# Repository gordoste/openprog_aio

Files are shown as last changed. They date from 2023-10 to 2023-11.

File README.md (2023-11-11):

# openprog_aio
All-in-one variant of Alberto Maccioni's wonderful Openprog PIC/AVR programmer (http://openprog.altervista.org/).

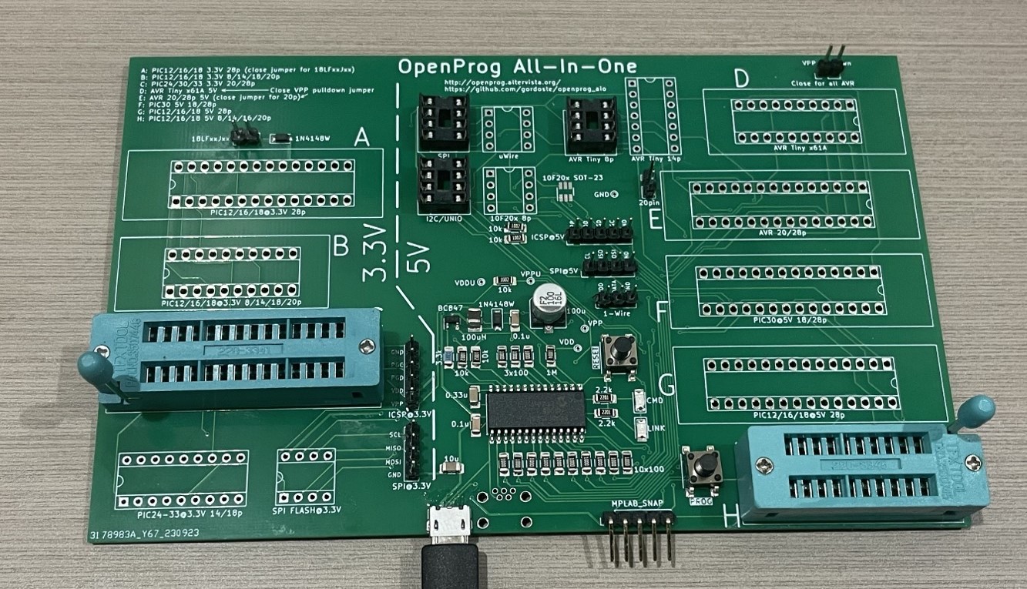
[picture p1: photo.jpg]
Photo of board


## Benefits

For low-voltage programming, the big advantage of this programmer over something like the MPLAB Snap is that it can provide power to the target device, and all of the surrounding circuitry (bypass caps, etc.) is built onto the board. You just plug in a device and program it.

The programmer is also fully capable of high-voltage programming. This is essential if you need to program an older device, and it also means you can use the MCLR pin as an extra I/O, which can be very handy on low-pin-count devices.

This version is aimed at allowing you to get started for the lowest cost and without making your own PCBs. Therefore, the following changes have been made from the original project:

* No adapter boards - just one board, making it cheaper to order from PCB fabrication shops.
* Board is still reasonable size at 158x100mm - approx twice the size of the original project's main board
* Designed to be easily hand-soldered, with 1206 size SMD components. The trickiest thing to solder is the USB socket. You shouldn't need any special equipment if you have clear vision and good lighting - just 0.3mm solder, flux paste and de-soldering braid. NOTE: If you are hand-soldering, it is recommended to use a USB Mini-B socket - see [Part List](#part-list).
* Documentation is on the board, including clear delineation between 5V/3.3V
* Ability to use ZIF sockets for all 20/28 pin sockets if desired.
* PROG button can be used even if device is programmed in low-voltage mode (previously it was attached to RE3/#MCLR)
* ICSP inputs match the MPLAB Snap pinout (different from PICKit).

Please note that the 40-pin Wide DIP sockets have been removed as those devices are rarely used now and took up too much room. If you want to program those devices, you can easily connect the ICSP output to a breadboard.

## Before you start

You need temporary access to a PIC programmer to construct this project. If you don't have a friend with a programmer, the MPLAB Snap is the cheapest commercial option.

## Schematic

The schematic is [here](schematic.pdf).

## Firmware

The original firmware uses unsupported tooling (MCC). I have ported the firmware to MPLAB X and it is available at <https://github.com/gordoste/openprog>. All testing of this board is conducted using this firmware, and testing status of the board/firmware combo can be found at the firmware repository.

## Part List

You can copy and paste [this part list](bom/partlist.txt) into Mouser's BOM tool to order the passive components and semiconductors. In addition to those, you will need the following which are best ordered from AliExpress or similar:
1. IC sockets. You may wish to only populate the sockets you use. Here is a list of all of the sockets:
   | Socket ID | Socket pin count | Device family | Voltage | Device pin count | Can be ZIF? |
   | ----------|------------------|---------------|---------|------------------|-------------|
   | A | 28 | PIC12/16/18 | 3.3V | 28 | Y  |
   | B | 20 | PIC12/16/18 | 3.3V | 8/14/18/20 | Y |
   | C | 28 | PIC24/30/33 | 3.3V | 20/28 | Y |
   | D | 20 | AVR Tiny x61A | 5V | 20 | Y |
   | E | 28 | AVR | 5V | 20/28 | Y |
   | F | 28 | PIC30 | 5V | 18/28 | Y |
   | G | 28 | PIC12/16/18 | 5V | 28 | Y |
   | H | 20 | PIC12/16/18 | 5V | 8/14/16/20 | Y |
   | - | 18 | PIC24-33 | 3.3V | 14/18 | N |
   | - | 8  | SPI Flash | 3.3V | 8 | N |
   | - | 8  | SPI Flash | 5V | 8 | N |
   | - | 8  | uWire Flash | 5V | 8 | N |
   | - | 8  | I2C/UNIO Flash | 5V | 8 | N |
   | - | 8  | PIC 10F20x | 5V | 8 | N |
   | - | 8  | AVR Tiny | 5V | 8 | N |
   | - | 14 | AVR Tiny | 5V | 14 | N |
2. 2.54mm (0.1") pitch pin headers. 3 x 2-pin, 3 x 5-pin, 2 x 4-pin and 1 x 3-pin (all straight). Optionally, you can use a 90-degree header for the 5-pin MPLAB Snap connector.
3. one 6x6mm SMD push button for the PROG button (two if you choose to fit the RESET button)
4. USB socket - either thru-hole Mini-B (I got some from AliExpress which worked fine) or SMD Micro-B (GCT part # USB3076-30-A) (this has fine-pitch pins and is not easy to hand-solder).

## Construction Notes

Download the [ZIP file](https://github.com/gordoste/openprog_aio/releases/download/v1.0b/Openprog_All-in-one_1.0b.zip) containing the PCB gerber files and submit it to your favourite production house.

You can use [this interactive BOM](ibom.html) to assist in placing parts.

Assuming you are hand-soldering, solder the parts in the following order:
1. Back side: Transistors, diodes, resistors, capacitors, regulator
2. Front side: Transistors, diodes, resistors, LEDs, ceramic capacitors, inductor, PIC18F25K50, button(s), electrolytic cap, USB socket, pin headers.

Be careful to only apply a small amount of solder when soldering the USB socket, as it is very easy to create a bridge. Don't panic if you do - turn your soldering iron up a bit hotter than normal, apply a liberal amount of flux and then use desolder braid to try to get rid of __all__ of the solder from the bridged pins. Once it's cleaned up, try again with less solder.

After you've soldered everything, download the HEX file from the [firmware repository](https://github.com/gordoste/openprog) and program it onto the PIC. The marked "MPLAB_SNAP" connector matches the pinout of the Snap (as shown below) - if you're using a PICKit then you will need to utilise jumper wires to connect the programmer.

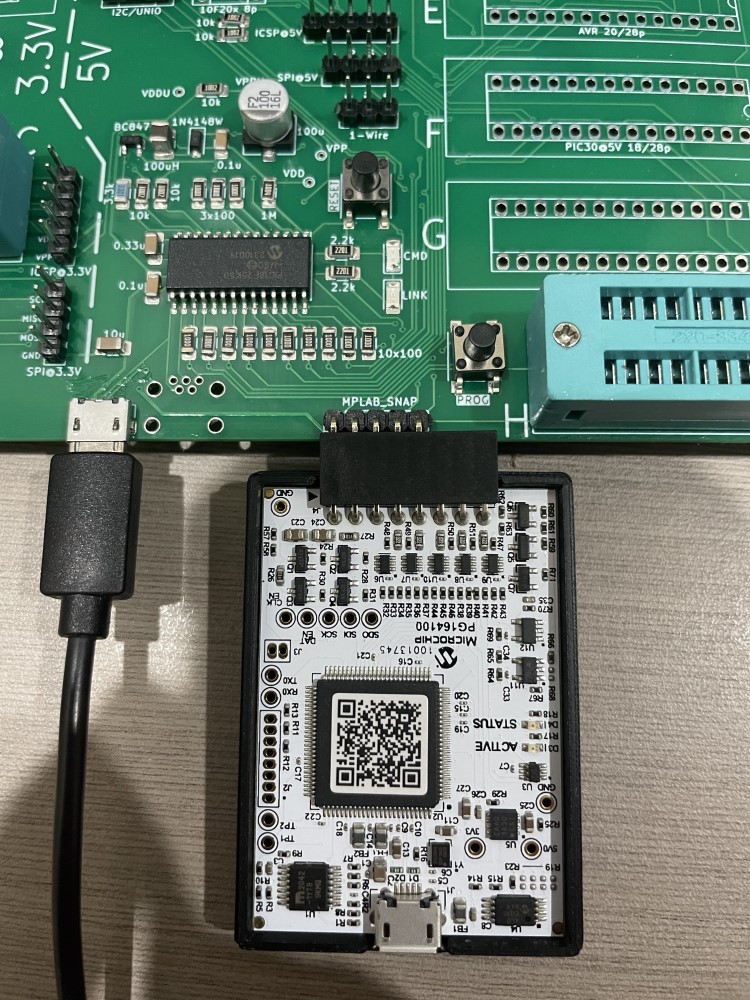
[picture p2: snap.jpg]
MPLAB Snap attached for programming


Assuming you've done everything right, when you plug it into your PC, it should show up as "Open Programmer" and the openprog GUI should be able to talk to it. I recommend using the command line "op" tool with the "-HWtest" option to run through basic checks before actually trying to program anything. See the [openprog webpage](http://openprog.altervista.org/) for more information.

## Usage Notes

### Programming 3.3V I2C EEPROMs

The original project did not provide a socket for this, and I have not yet added one. You can use the SPI@3.3V pin header and connect the following:
|Header pin|Device pin|
|---|---|
|GND|GND (4)|
|SCL|SCL (6)|
|MISO|SDA (5)|

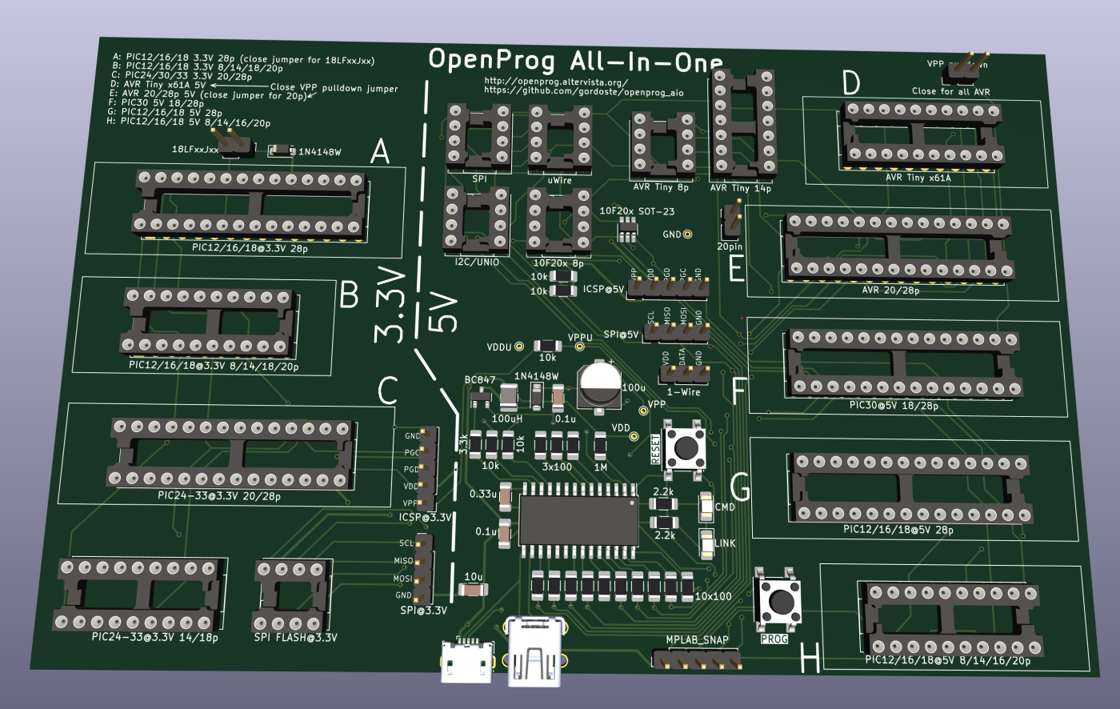
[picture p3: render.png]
Board render in KiCAD


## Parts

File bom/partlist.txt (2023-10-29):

579-PIC18F25K50-I/SO	1
80-C1206C104K5R7210	14
187-CL31A106KOHNNNE	4
187-CL31B334KBFNNNE	1
652-CR1206FX-1004ELF	1
652-CR1206FX-3303ELF	2
652-CR1206FX-1003ELF	1
652-CR1206FX-2202ELF	1
652-CR1206FX-1202ELF	1
652-CR1206FX-1002ELF	8
652-CR1206FX-2201ELF	2
791-RMC1/8K1000FTP	13
652-CR1206FX-1001ELF	7
652-CR1206FX-3301ELF	1
963-LBC3225T101KR	1
833-1N4148W-TP	9
710-150120BS75000	1
710-150120RS75000	1
863-BC857CLT1G	2
771-BC847B-T/R	2
710-865080343009	1

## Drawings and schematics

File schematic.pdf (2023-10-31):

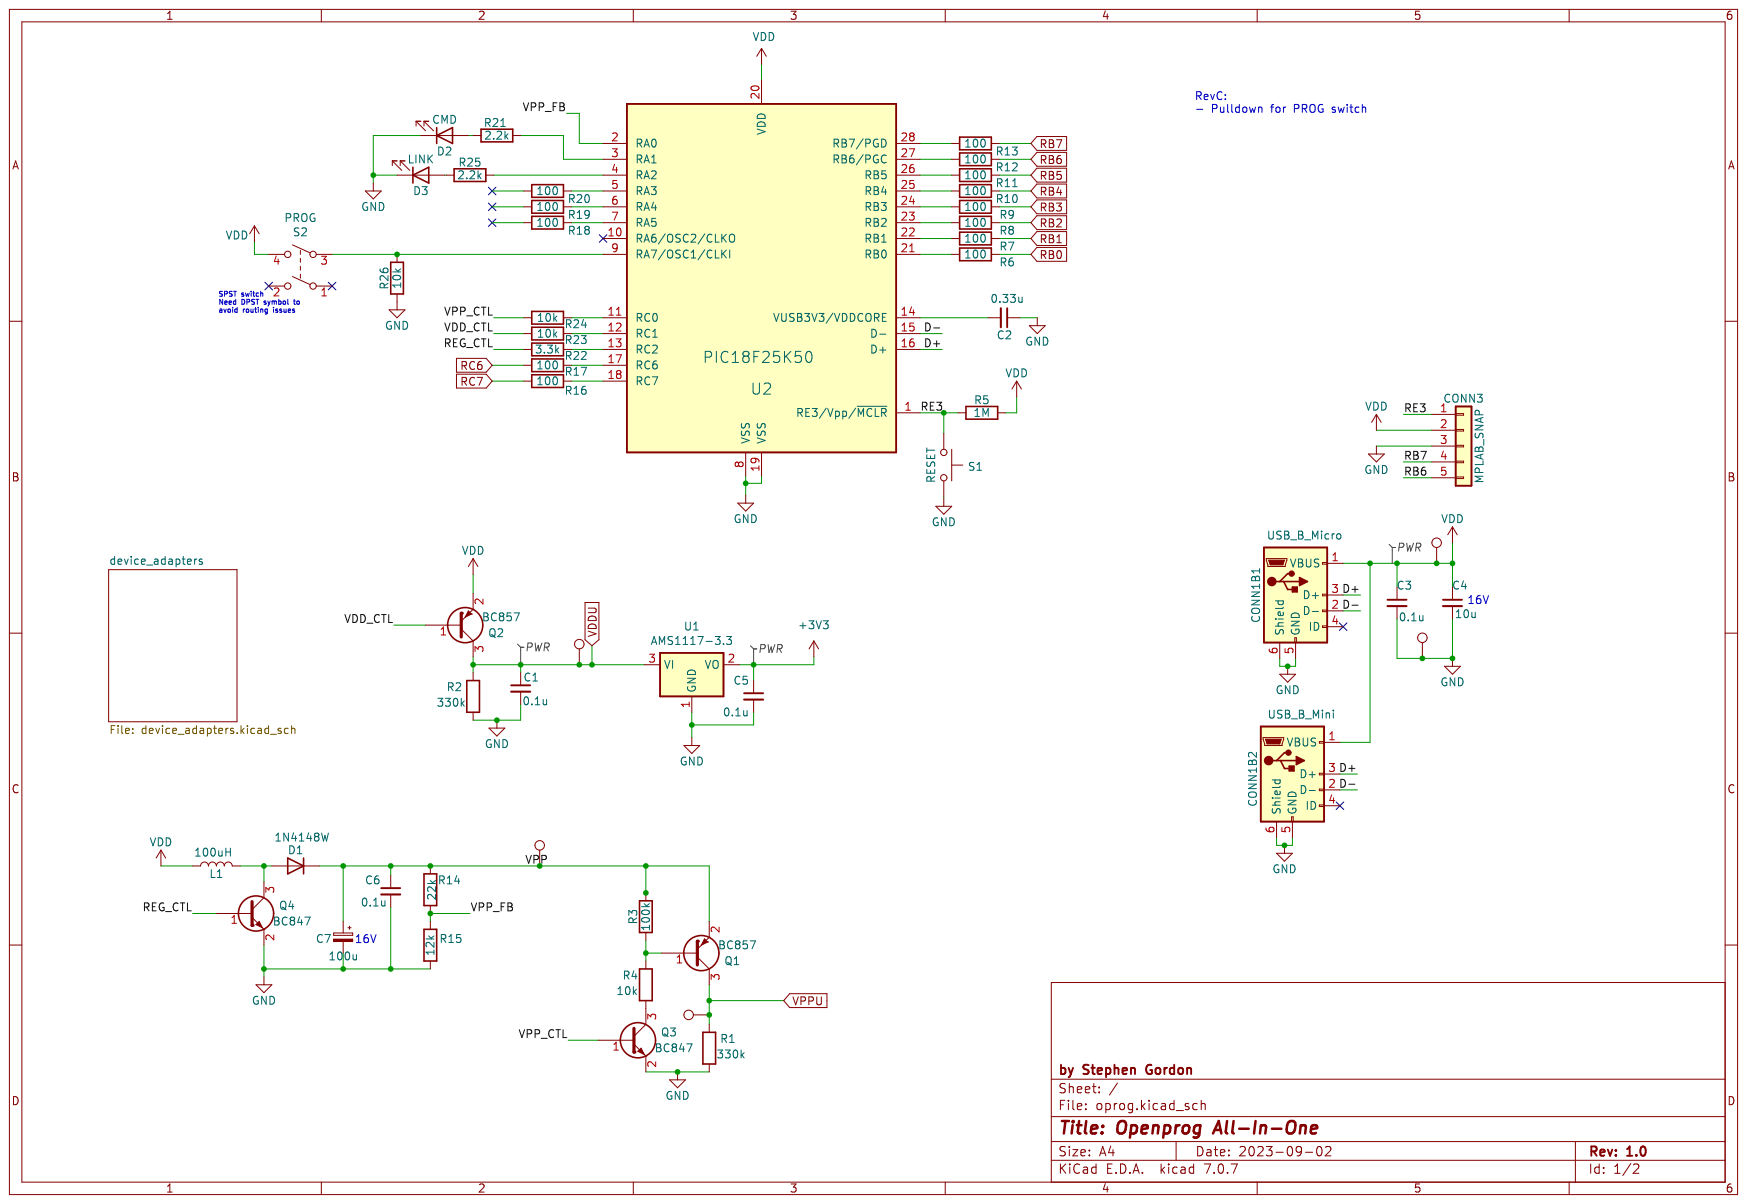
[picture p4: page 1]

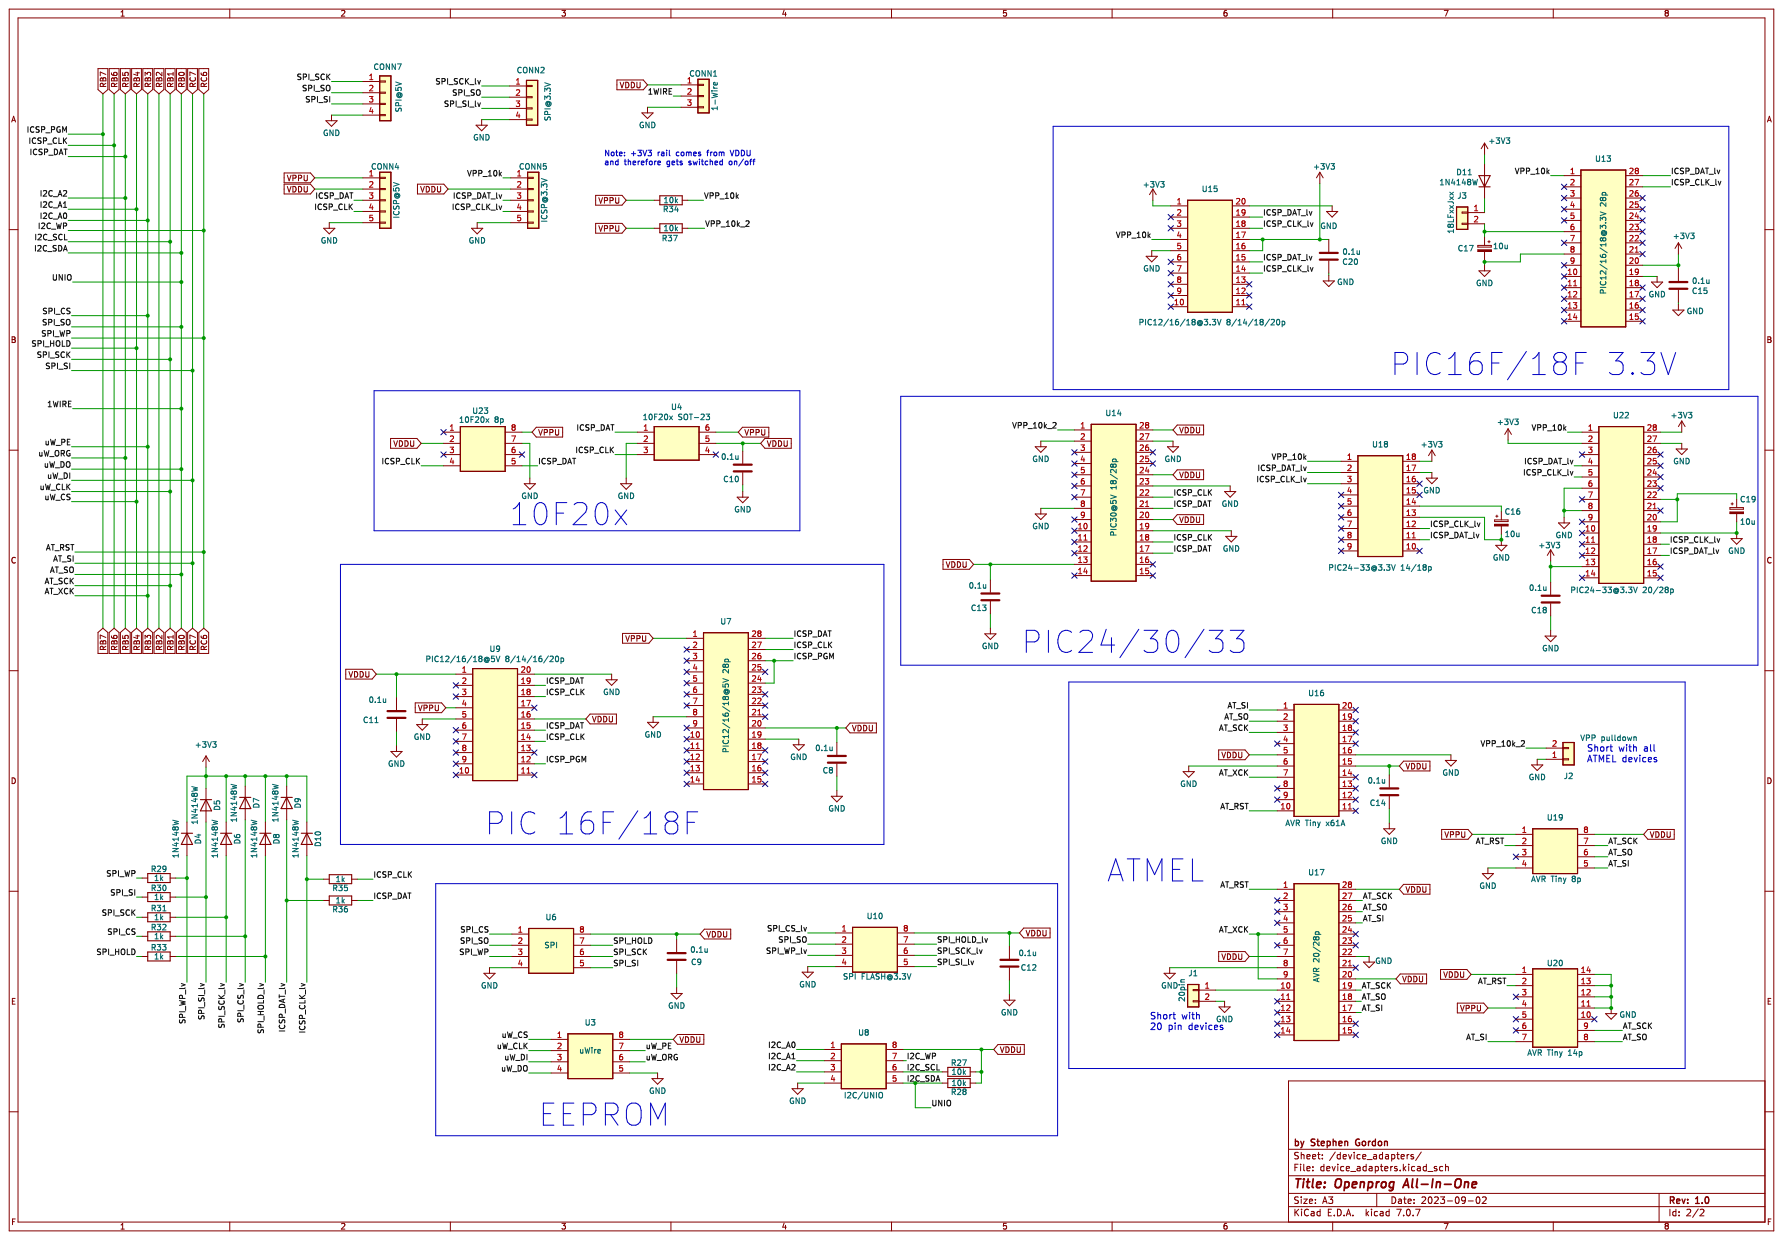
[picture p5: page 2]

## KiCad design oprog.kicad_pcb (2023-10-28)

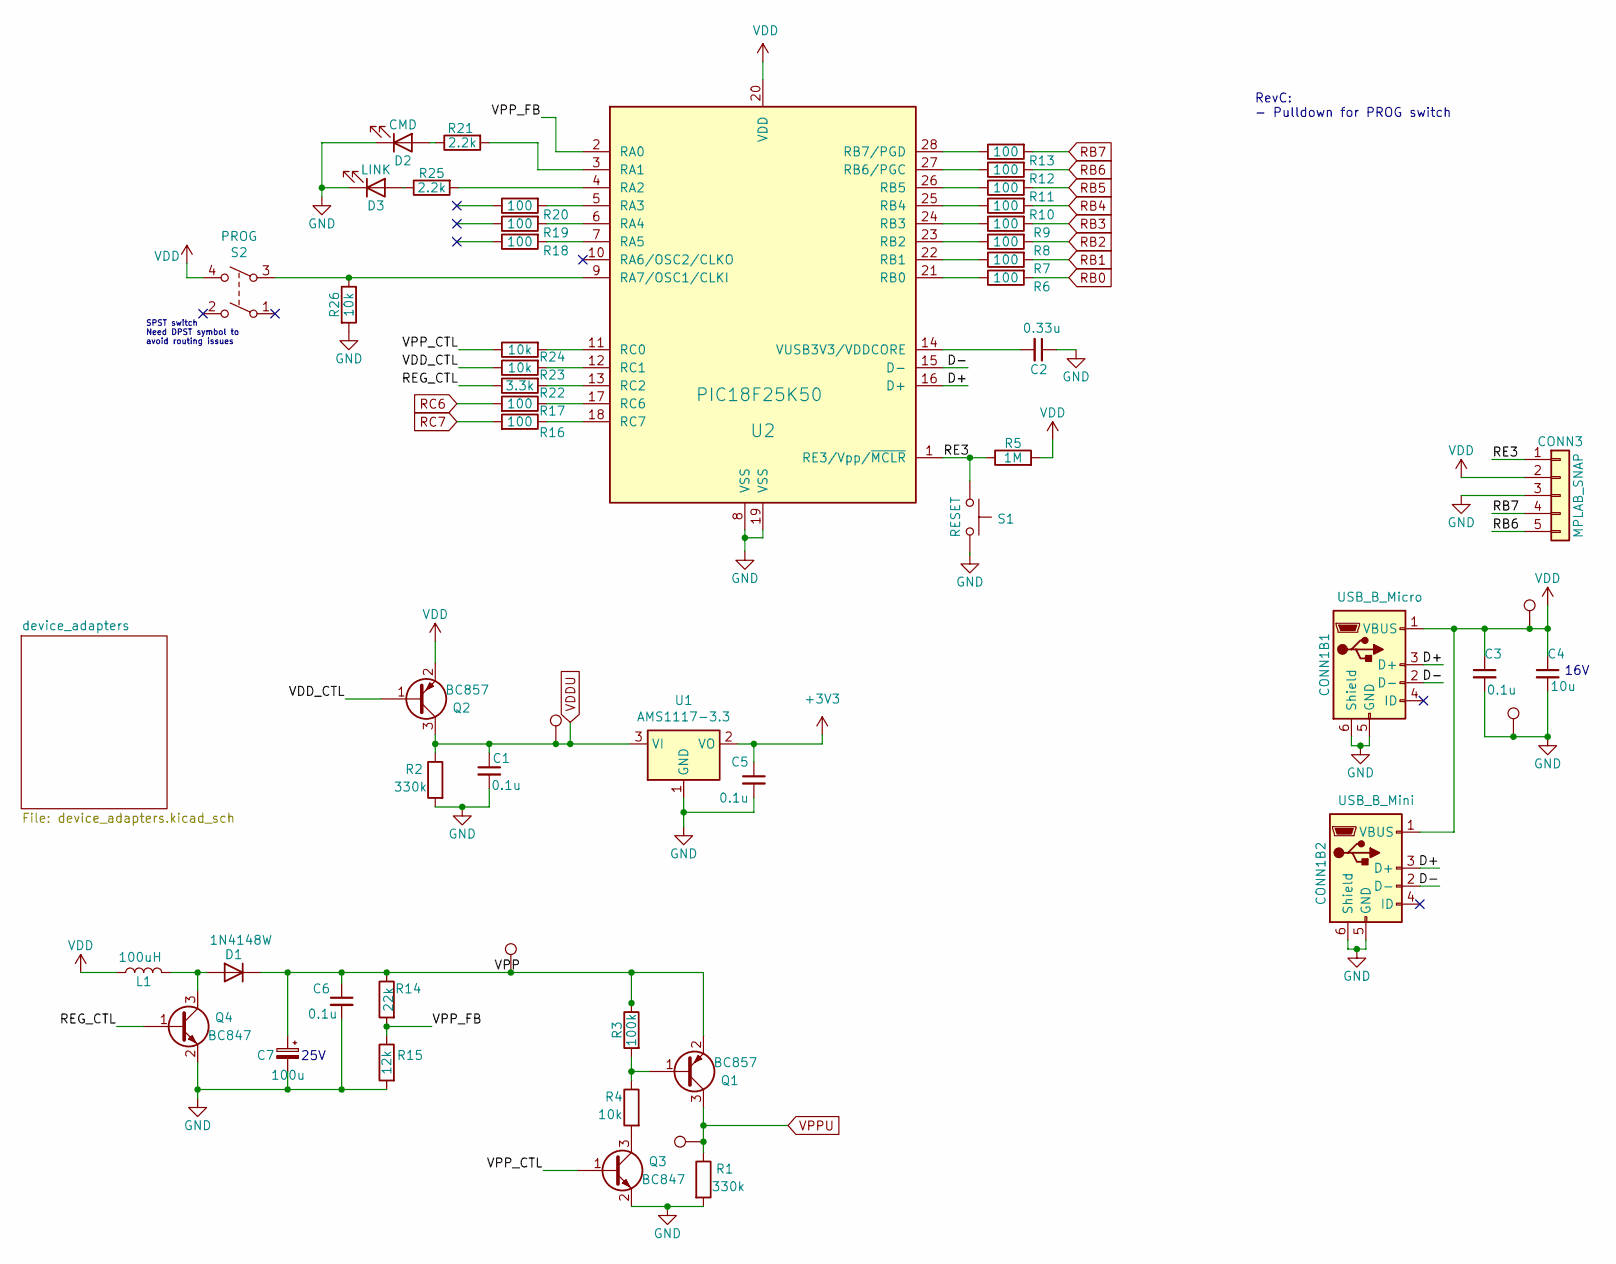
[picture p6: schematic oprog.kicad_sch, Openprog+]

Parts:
C1, C3, C5, C6: 0.1u; C_1206_3216Metric_Pad1.33x1.80mm_HandSolder
C2: 0.33u; C_1206_3216Metric_Pad1.33x1.80mm_HandSolder
C4: 10u; C_1206_3216Metric_Pad1.33x1.80mm_HandSolder
C7: 100u; CP_Elec_6.3x5.7
CONN1B1: USB_B_Micro; USB_Micro-B_GCT_USB3076-30-A
CONN1B2: USB_B_Mini; USB_Mini_Type_B_Aliexpress
CONN3: MPLAB_SNAP; PinHeader_1x05_P2.54mm_Vertical
D1: 1N4148W; D_SOD-123
D2: CMD; LED_1206_3216Metric_Pad1.42x1.75mm_HandSolder
D3: LINK; LED_1206_3216Metric_Pad1.42x1.75mm_HandSolder
L1: 100uH; L_1210_3225Metric_Pad1.42x2.65mm_HandSolder
Q1, Q2: BC857; SOT-23
Q3, Q4: BC847; SOT-23
R1, R2: 330k; R_1206_3216Metric_Pad1.30x1.75mm_HandSolder
R3: 100k; R_1206_3216Metric_Pad1.30x1.75mm_HandSolder
R4, R23, R24, R26: 10k; R_1206_3216Metric_Pad1.30x1.75mm_HandSolder
R5: 1M; R_1206_3216Metric_Pad1.30x1.75mm_HandSolder
R6, R7, R8, R9, R10, R11, R12, R13, R16, R17, R18, R19, R20: 100; R_1206_3216Metric_Pad1.30x1.75mm_HandSolder
R14: 22k; R_1206_3216Metric_Pad1.30x1.75mm_HandSolder
R15: 12k; R_1206_3216Metric_Pad1.30x1.75mm_HandSolder
R21, R25: 2.2k; R_1206_3216Metric_Pad1.30x1.75mm_HandSolder
R22: 3.3k; R_1206_3216Metric_Pad1.30x1.75mm_HandSolder
S1: RESET; SW_Push_1P1T_NO_6x6mm_2pads
S2: PROG; SW_Push_1P1T_NO_6x6mm_4pads
TP1: VPPU; TestPoint_THTPad_D1.0mm_Drill0.5mm
TP2: GND; TestPoint_THTPad_D1.0mm_Drill0.5mm
TP3: VDD; TestPoint_THTPad_D1.0mm_Drill0.5mm
TP7: VPP; TestPoint_THTPad_D1.0mm_Drill0.5mm
TP8: VDDU; TestPoint_THTPad_D1.0mm_Drill0.5mm
U1: AMS1117-3.3; SOT-223-3_TabPin2
U2: PIC18F25K50; SOIC-28W_7.5x17.9mm_P1.27mm

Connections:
+3V3: C5.1, U1.2 (VO); also elsewhere on the board
/D+: CONN1B1.3 (D+), CONN1B2.3 (D+), U2.16 (D+)
/D-: CONN1B1.2 (D-), CONN1B2.2 (D-), U2.15 (D-)
/RE3: CONN3.1, R5.1, S1.2, U2.1 (RE3/Vpp/~MCLR)
/REG_CTL: Q4.1 (B), R22.1
/VDD_CTL: Q2.1 (B), R23.1
/VPP: C6.1, C7.1, D1.1 (K), Q1.2 (E), R3.1, R14.1, TP7.1
/VPP_CTL: Q3.1 (B), R24.1
/VPP_FB: R14.2, R15.1, U2.2 (RA0)
GND: C1.2, C2.1, C3.2, C4.2, C5.2, C6.2, C7.2, CONN1B1.5 (GND), CONN1B1.6 (Shield), CONN1B2.5 (GND), CONN1B2.6 (Shield), CONN3.3, D2.1 (K), D3.1 (K), Q3.2 (E), Q4.2 (E), R1.2, R2.2, R15.2, R26.2, S1.1, TP2.1, U1.1 (GND), U2.8 (VSS), U2.19 (VSS); also elsewhere on the board
unnamed: D1.2 (A), L1.1, Q4.3 (C)
unnamed: D2.2 (A), R21.1
unnamed: D3.2 (A), R25.1
unnamed: Q1.1 (B), R3.2, R4.1
unnamed: Q3.3 (C), R4.2
unnamed: R21.2, U2.3 (RA1)
unnamed: R25.2, U2.4 (RA2)
unnamed: R20.2, U2.5 (RA3)
unnamed: R19.2, U2.6 (RA4)
unnamed: R18.2, U2.7 (RA5)
unnamed: R26.1, S2.3, U2.9 (RA7/OSC1/CLKI)
unnamed: R6.1, U2.21 (RB0)
unnamed: R7.1, U2.22 (RB1)
unnamed: R8.1, U2.23 (RB2)
unnamed: R9.1, U2.24 (RB3)
unnamed: R10.1, U2.25 (RB4)
unnamed: R11.1, U2.26 (RB5)
unnamed: R12.1, U2.27 (RB6/PGC)
unnamed: R13.1, U2.28 (RB7/PGD)
unnamed: R24.2, U2.11 (RC0)
unnamed: R23.2, U2.12 (RC1)
unnamed: R22.2, U2.13 (RC2)
unnamed: R17.1, U2.17 (RC6)
unnamed: R16.1, U2.18 (RC7)
unnamed: C2.2, U2.14 (VUSB3V3/VDDCORE)
RB0: R6.2; also elsewhere on the board
RB1: R7.2; also elsewhere on the board
RB2: R8.2
RB3: R9.2; also elsewhere on the board
RB4: R10.2; also elsewhere on the board
RB5: R11.2; also elsewhere on the board
RB6: CONN3.5, R12.2; also elsewhere on the board
RB7: CONN3.4, R13.2; also elsewhere on the board
RC6: R17.2; also elsewhere on the board
RC7: R16.2; also elsewhere on the board
VDD: C3.1, C4.1, CONN1B1.1 (VBUS), CONN1B2.1 (VBUS), CONN3.2, L1.2, Q2.2 (E), R5.2, S2.4, TP3.1, U2.20 (VDD)
VDDU: C1.1, Q2.3 (C), R2.1, TP8.1, U1.3 (VI); also elsewhere on the board
VPPU: Q1.3 (C), R1.1, TP1.1; also elsewhere on the board

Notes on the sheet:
RevC: - Pulldown for PROG switch
SPST switch Need DPST symbol to avoid routing issues
16V
25V

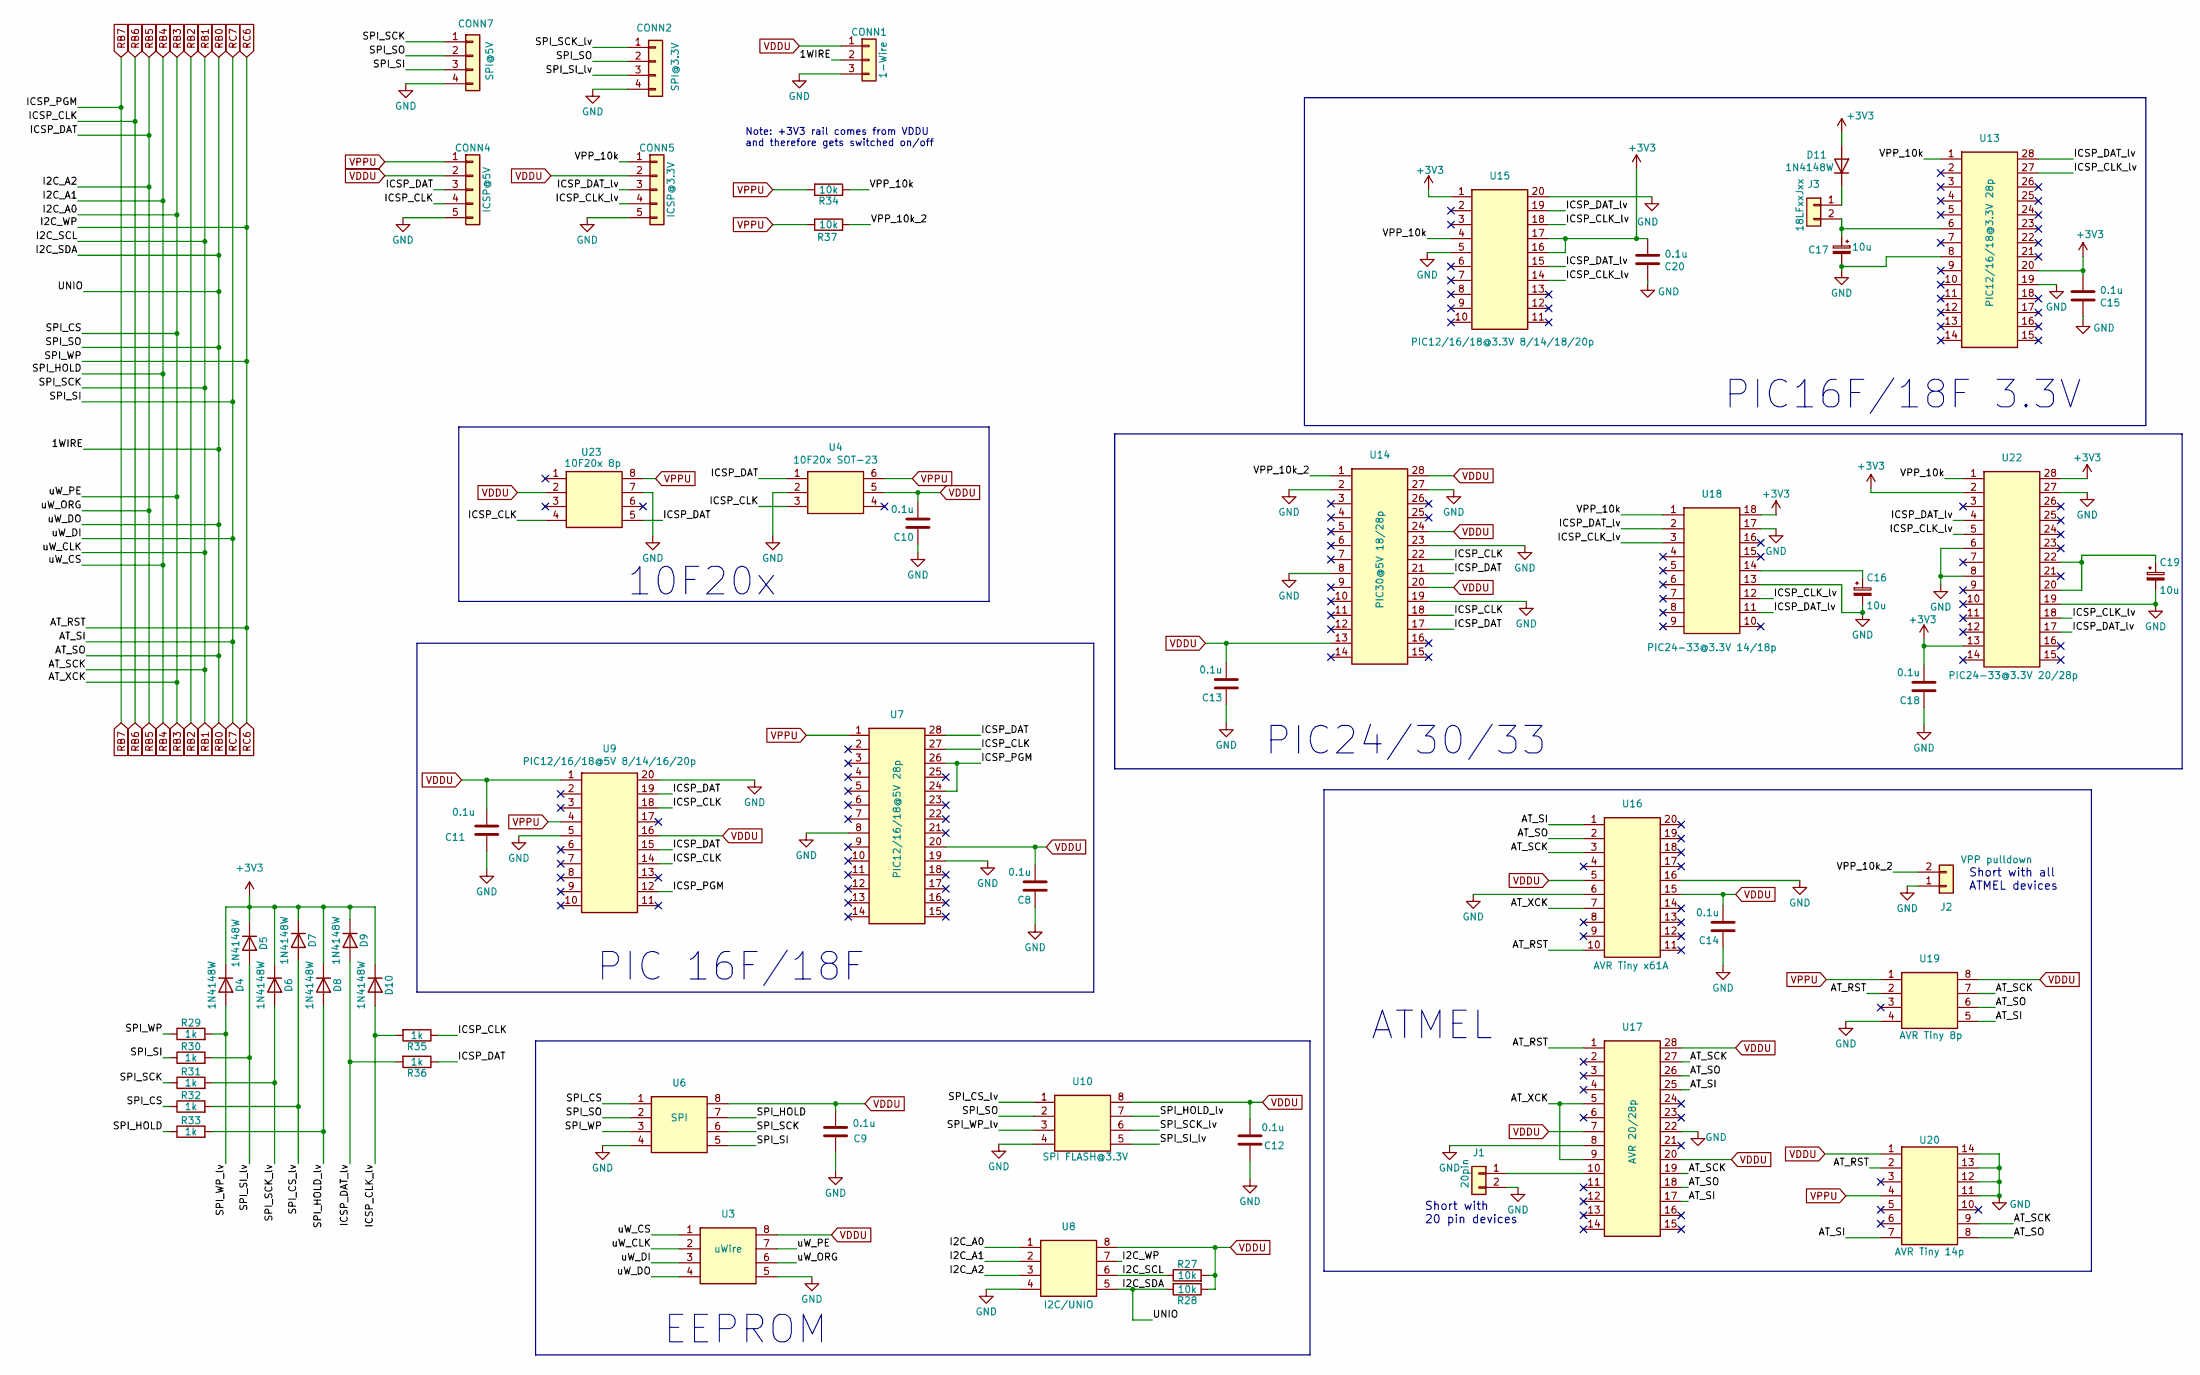
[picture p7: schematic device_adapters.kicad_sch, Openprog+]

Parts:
C8, C9, C10, C11, C12, C13, C14, C15, C18, C20: 0.1u; C_1206_3216Metric_Pad1.33x1.80mm_HandSolder
C16, C17, C19: 10u; C_1206_3216Metric_Pad1.33x1.80mm_HandSolder
CONN1: 1-Wire; PinHeader_1x03_P2.54mm_Vertical
CONN2: SPI@3.3V; PinHeader_1x04_P2.54mm_Vertical
CONN4: ICSP@5V; PinHeader_1x05_P2.54mm_Vertical
CONN5: ICSP@3.3V; PinHeader_1x05_P2.54mm_Vertical
CONN7: SPI@5V; PinHeader_1x04_P2.54mm_Vertical
D4, D5, D6, D7, D8, D9, D10, D11: 1N4148W; D_SOD-123
J1: 20pin; PinHeader_1x02_P2.54mm_Vertical
J2: VPP pulldown; PinHeader_1x02_P2.54mm_Vertical
J3: 18LFxxJxx; PinHeader_1x02_P2.54mm_Vertical
R27, R28, R34, R37: 10k; R_1206_3216Metric_Pad1.30x1.75mm_HandSolder
R29, R30, R31, R32, R33, R35, R36: 1k; R_1206_3216Metric_Pad1.30x1.75mm_HandSolder
U3: uWire; DIP-8_W7.62mm_Socket
U4: 10F20x SOT-23; SOT-23-6_Handsoldering
U6: SPI; DIP-8_W7.62mm_Socket
U7: PIC12/16/18@5V 28p; ZIFSocket_28p_W7.62mm
U8: I2C/UNIO; DIP-8_W7.62mm_Socket
U9: PIC12/16/18@5V 8/14/16/20p; ZIFSocket_20p_W7.62mm
U10: SPI FLASH@3.3V; DIP-8_W7.62mm_Socket
U13: PIC12/16/18@3.3V 28p; ZIFSocket_28p_W7.62mm
U14: PIC30@5V 18/28p; ZIFSocket_28p_W7.62mm
U15: PIC12/16/18@3.3V 8/14/18/20p; ZIFSocket_20p_W7.62mm
U16: AVR Tiny x61A; ZIFSocket_20p_W7.62mm
U17: AVR 20/28p; ZIFSocket_28p_W7.62mm
U18: PIC24-33@3.3V 14/18p; DIP-18_W7.62mm_Socket
U19: AVR Tiny 8p; DIP-8_W7.62mm_Socket
U20: AVR Tiny 14p; DIP-14_W7.62mm_Socket
U22: PIC24-33@3.3V 20/28p; ZIFSocket_28p_W7.62mm
U23: 10F20x 8p; DIP-8_W7.62mm_Socket

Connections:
+3V3: C15.2, C18.2, C20.2, D4.1 (K), D5.1 (K), D6.1 (K), D7.1 (K), D8.1 (K), D9.1 (K), D10.1 (K), D11.2 (A), U13.20, U15.1, U15.16, U15.17, U18.18, U22.2, U22.13, U22.28; also elsewhere on the board
/device_adapters/ICSP_CLK_lv: CONN5.4, D10.2 (A), R35.2, U13.27, U15.14, U15.18, U18.3, U18.12, U22.5, U22.18
/device_adapters/ICSP_DAT_lv: CONN5.3, D9.2 (A), R36.2, U13.28, U15.15, U15.19, U18.2, U18.11, U22.4, U22.17
/device_adapters/SPI_CS_lv: D7.2 (A), R32.2, U10.1
/device_adapters/SPI_HOLD_lv: D8.2 (A), R33.2, U10.7
/device_adapters/SPI_SCK_lv: CONN2.1, D6.2 (A), R31.2, U10.6
/device_adapters/SPI_SI_lv: CONN2.3, D5.2 (A), R30.2, U10.5
/device_adapters/SPI_WP_lv: D4.2 (A), R29.2, U10.3
/device_adapters/VPP_10k: CONN5.1, R34.1, U13.1, U15.4, U18.1, U22.1
/device_adapters/VPP_10k_2: J2.2, R37.2, U14.1
GND: C8.1, C9.1, C10.1, C11.1, C12.1, C13.1, C14.1, C15.1, C16.2, C17.2, C18.1, C19.2, C20.1, CONN1.3, CONN2.4, CONN4.5, CONN5.5, CONN7.4, J1.2, J2.1, U3.5, U4.2, U6.4, U7.8, U7.19, U8.4, U9.5, U9.20, U10.4, U13.8, U13.19, U14.2, U14.8, U14.19, U14.23, U14.27, U15.5, U15.20, U16.6, U16.16, U17.8, U17.22, U18.13, U18.17, U19.4, U20.11, U20.12, U20.13, U20.14, U22.6, U22.8, U22.19, U22.27, U23.7; also elsewhere on the board
unnamed: C16.1, U18.14
unnamed: C19.1, U22.20, U22.22
unnamed: D11.1 (K), J3.1
unnamed: J1.1, U17.10
unnamed: C17.1, J3.2, U13.6
RB0: CONN1.2, CONN2.2, CONN7.2, R28.2, U3.4, U6.2, U8.5, U10.2, U16.2, U17.18, U17.26, U19.6, U20.8; also elsewhere on the board
RB1: CONN7.1, R27.1, R31.1, U3.2, U6.6, U8.6, U16.3, U17.19, U17.27, U19.7, U20.9; also elsewhere on the board
RB3: R32.1, U3.7, U6.1, U8.1, U16.7, U17.5, U17.9; also elsewhere on the board
RB4: R33.1, U3.1, U6.7, U8.2; also elsewhere on the board
RB5: CONN4.3, R36.1, U3.6, U4.1, U7.28, U8.3, U9.15, U9.19, U14.17, U14.21, U23.5; also elsewhere on the board
RB6: CONN4.4, R35.1, U4.3, U7.27, U9.14, U9.18, U14.18, U14.22, U23.4; also elsewhere on the board
RB7: U7.24, U7.26, U9.12; also elsewhere on the board
RC6: R29.1, U6.3, U8.7, U16.10, U17.1, U19.2, U20.2; also elsewhere on the board
RC7: CONN7.3, R30.1, U3.3, U6.5, U16.1, U17.17, U17.25, U19.5, U20.7; also elsewhere on the board
VDDU: C8.2, C9.2, C10.2, C11.2, C12.2, C13.2, C14.2, CONN1.1, CONN4.2, CONN5.2, R27.2, R28.1, U3.8, U4.5, U6.8, U7.20, U8.8, U9.1, U9.16, U10.8, U14.13, U14.20, U14.24, U14.28, U16.5, U16.15, U17.7, U17.20, U17.28, U19.8, U20.1, U23.2; also elsewhere on the board
VPPU: CONN4.1, R34.2, R37.1, U4.6, U7.1, U9.4, U19.1, U20.4, U23.8; also elsewhere on the board

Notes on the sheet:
Short with all ATMEL devices
Note: +3V3 rail comes from VDDU and therefore gets switched on/off
PIC16F/18F 3.3V
10F20x
EEPROM
Short with 20 pin devices
PIC24/30/33
PIC 16F/18F
ATMEL

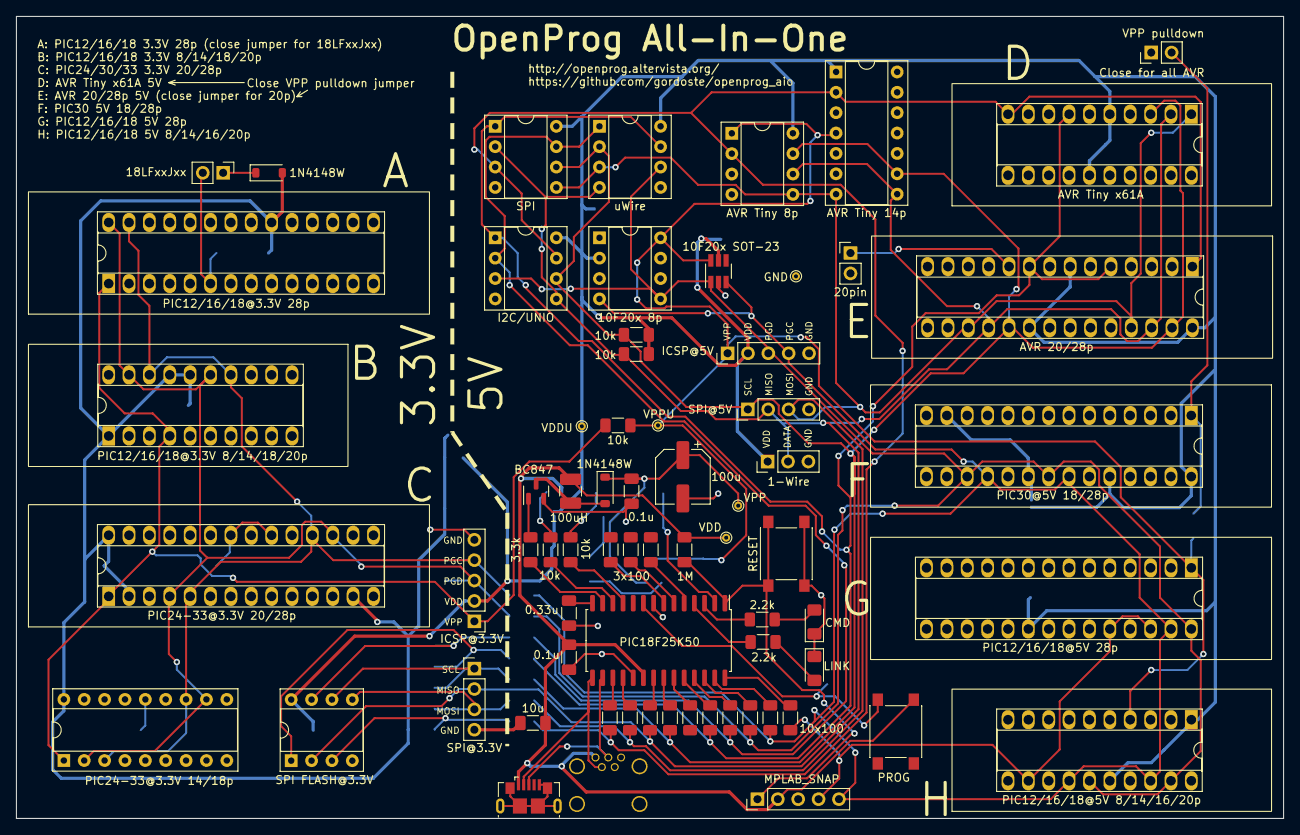
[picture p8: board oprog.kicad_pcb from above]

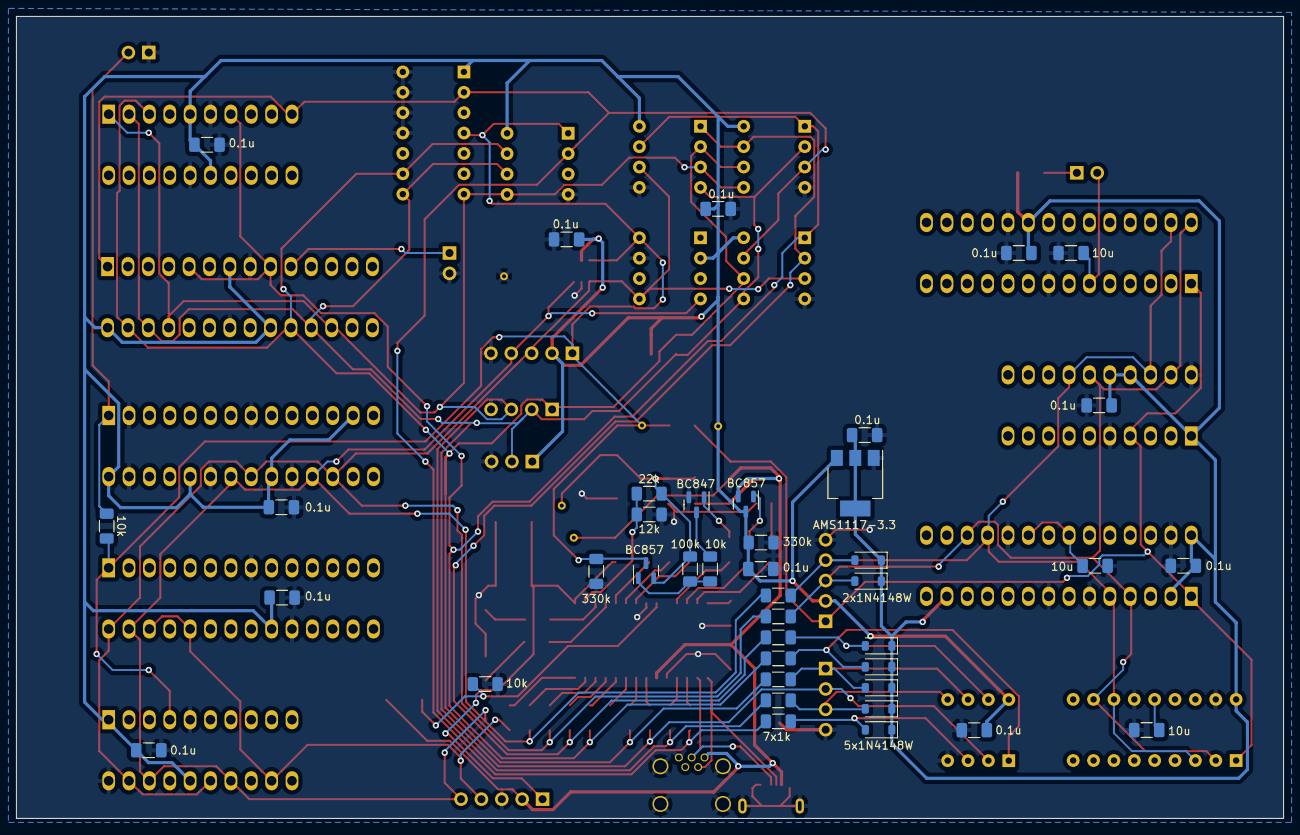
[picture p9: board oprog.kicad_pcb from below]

Board: 2 copper layers, 158.0 x 100.0 mm, 110 parts (41 on the bottom side), 61 nets.

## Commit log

2023-10-28 Initial release - v1.0b
    [device_adapters.kicad_sch, openprog_testing.xlsx, oprog.kicad_pcb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]
2023-10-28 Add BOM
2023-10-28 Add BOM to README
2023-10-28 Remove old BOM
2023-10-31 Add schematic
    [device_adapters.kicad_sch, oprog.kicad_sch]
2023-10-31 Add schematic to README
2023-11-09 Remove testing spreadsheet
    [openprog_testing.xlsx]
2023-11-10 Move board photo to top, add photo of Snap
2023-11-10 Add board render
2023-11-11 Explain how to program 3.3V I2C EEPROMs
